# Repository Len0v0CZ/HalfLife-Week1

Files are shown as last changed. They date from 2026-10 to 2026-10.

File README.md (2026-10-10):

# Macro Keyboard

A compact macro keyboard featuring 3 keys and 1 rotary encoder for task automation.
## Components
- Raspberry Pi Pico
- 3x Mechanical Switches
- 1x KY-040 Rotary Encoder
- Custom PCB
- 3D-printed case (base and lid)

Case
PCB

## Hardware Assembly
1. Solder the Pico, switches, and encoder to the PCB.
2. Mount the assembled PCB into the 3D-printed base using the M3 sized studs.
3. Attach the lid.

## Software Setup
1. Install CircuitPython on the Raspberry Pi Pico, more precisely it uses `adafruit_hid` library.
2. Save the Python script as `code.py` in the root directory.

## Usage
The rotary encoder adjusts the system volume and its button toggles mute. The three mechanical switches can be bound in `code.py`.

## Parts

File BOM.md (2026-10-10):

# Macro keyboard – bill of materials

<!-- Generated by Half Life from project cmuvl2h3h01gk01pys8nkxjlp. Edits here are overwritten on the next sync. -->
<!-- Generated: 2026-10-10T14:33:19.368Z -->

> [!NOTE]
> This parts list is mirrored from [Half Life](https://halflife.hackclub.com). Editing it here will not change the platform's copy, and the next sync overwrites this file.

| Week | Tier | Parts funding |
| --- | --- | --- |
| Week 1 | Tier 1 | $30.00 |

| Part | What it's for | Qty | Unit | Total | Vendor |
| --- | --- | --- | --- | --- | --- |
| [Raspberry Pico](https://rpishop.cz/raspberry-pi-pico/5117-raspberry-pi-pico.html) | main control board | 1 | $5.00 | $5.00 | [RpiShop](https://rpishop.cz/raspberry-pi-pico/5117-raspberry-pi-pico.html) |
| [Rotary encoder](https://rpishop.cz/enkodery/1329-rotacni-enkoder-ky-040-s-tlacitkem.html) | Volume control | 1 | $2.00 | $2.00 | [Rpishop](https://rpishop.cz/enkodery/1329-rotacni-enkoder-ky-040-s-tlacitkem.html) |
| [PCB](https://cart.jlcpcb.com/quote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) | the main board | 1 | $4.00 | $4.00 | [JLPCB](https://cart.jlcpcb.com/quote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) |
| **Parts subtotal** | — | — | — | **$11.00** | — |
| **Tax & shipping** | — | — | — | **$16.77** | — |
| **Total** | — | — | — | **$27.77** | — |

$2.23 left of the tier's funding.

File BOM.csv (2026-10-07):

Item | Part | Description | Quantity
1 | Custom PCB | PCB for the project | 1
2 | Cherry MX Switch | Mechanical switch | 3
3 | Rotary Encoder | Rotary encoder | 1
4 | Raspberry Pi Pico | microcontroller | 1
5 | 3D Printed Case Parts | Enclosure components | 1 set

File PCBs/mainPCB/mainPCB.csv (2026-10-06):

Reference | Qty | Value | DNP | Exclude from BOM | Exclude from Board | Exclude from Simulation | Exclude from Position Files | Footprint | Datasheet
A1 | 1 | RaspberryPi_Pico |  |  |  |  | ${EXCLUDE_FROM_POS_FILES} | Module:RaspberryPi_Pico_Common_Unspecified | https://datasheets.raspberrypi.com/pico/pico-datasheet.pdf
SW1 | 1 | RotaryEncoder_Switch |  |  |  |  | ${EXCLUDE_FROM_POS_FILES} | Rotary_Encoder:RotaryEncoder_Alps_EC11E-Switch_Vertical_H20mm_CircularMountingHoles
SW2,SW3,SW4 | 3 | SW_Push |  |  |  |  | ${EXCLUDE_FROM_POS_FILES} | Button_Switch_Keyboard:SW_Cherry_MX_1.00u_Plate

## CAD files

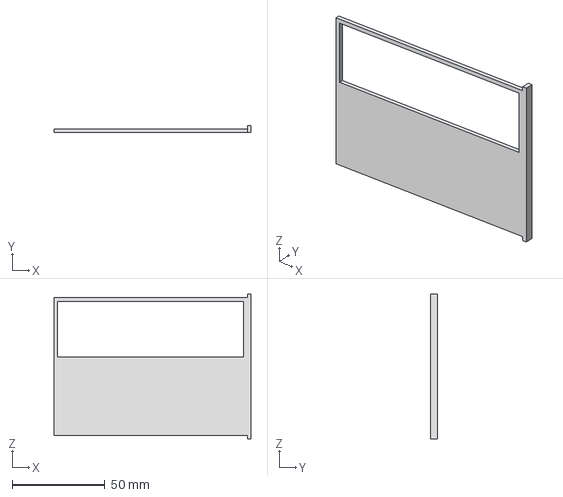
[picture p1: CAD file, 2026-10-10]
Case/STEPs/Lid.stp
106.0 x 4.00 x 78.0 mm

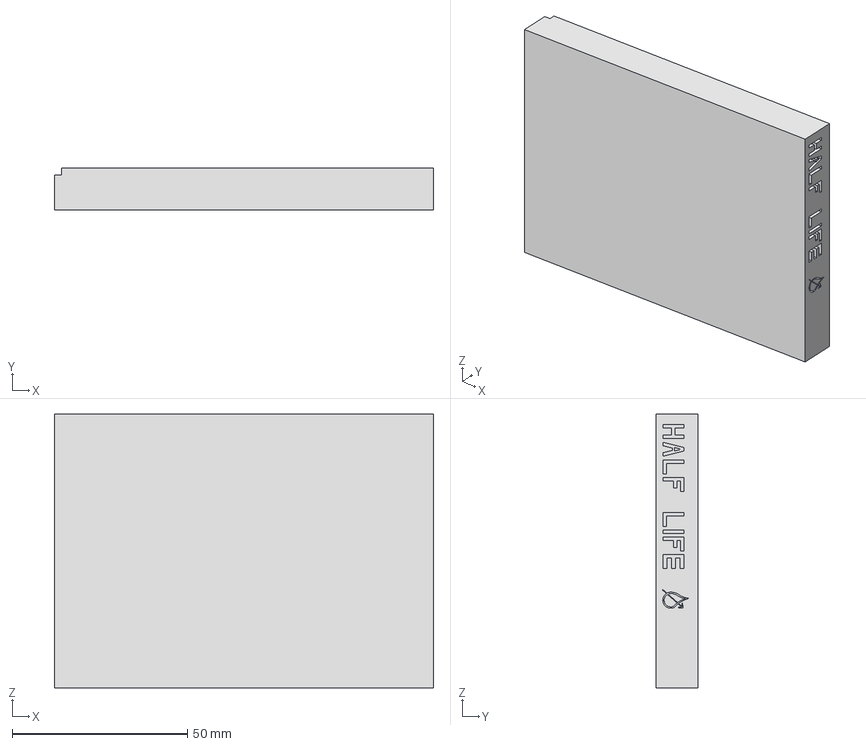
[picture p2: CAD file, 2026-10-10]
Case/STEPs/BasePlate.stp
108.0 x 12.0 x 78.0 mm

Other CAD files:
Case/Inventor/BasePlate.ipt
Case/Inventor/CASE.iam
Case/Inventor/Lid.ipt
Case/OldVersions/BasePlate.0005.ipt
Case/STLs/BasePlate.stl
Case/STLs/Lid.stl

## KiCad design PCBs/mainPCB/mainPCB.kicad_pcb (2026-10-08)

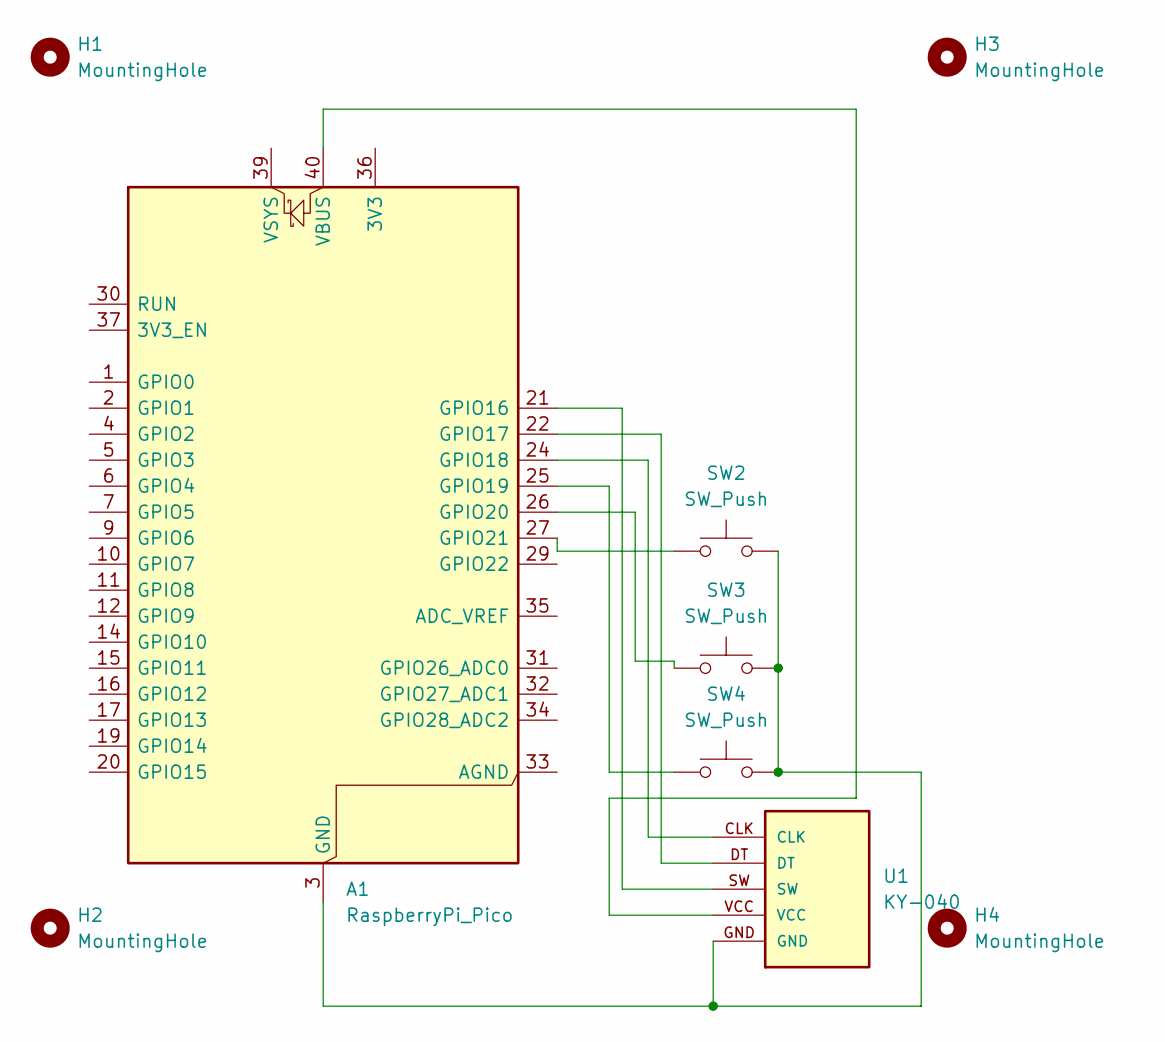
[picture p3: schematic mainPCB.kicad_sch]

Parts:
A1: RaspberryPi_Pico; RaspberryPi_Pico_Common_Unspecified
H1, H2, H3, H4: MountingHole; MountingHole_3.2mm_M3_DIN965
SW2, SW3, SW4: SW_Push; SW_Cherry_MX_1.00u_Plate
U1: KY-040; KY-040-PORT

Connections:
unnamed: A1.3 (GND), A1.8 (GND), A1.13 (GND), A1.18 (GND), A1.23 (GND), A1.28 (GND), A1.38 (GND), SW2.2, SW3.2, SW4.2, U1.GND
unnamed: A1.21 (GPIO16), U1.SW
unnamed: A1.22 (GPIO17), U1.DT
unnamed: A1.24 (GPIO18), U1.CLK
unnamed: A1.25 (GPIO19), SW4.1
unnamed: A1.26 (GPIO20), SW3.1
unnamed: A1.27 (GPIO21), SW2.1
unnamed: A1.40 (VBUS), U1.VCC

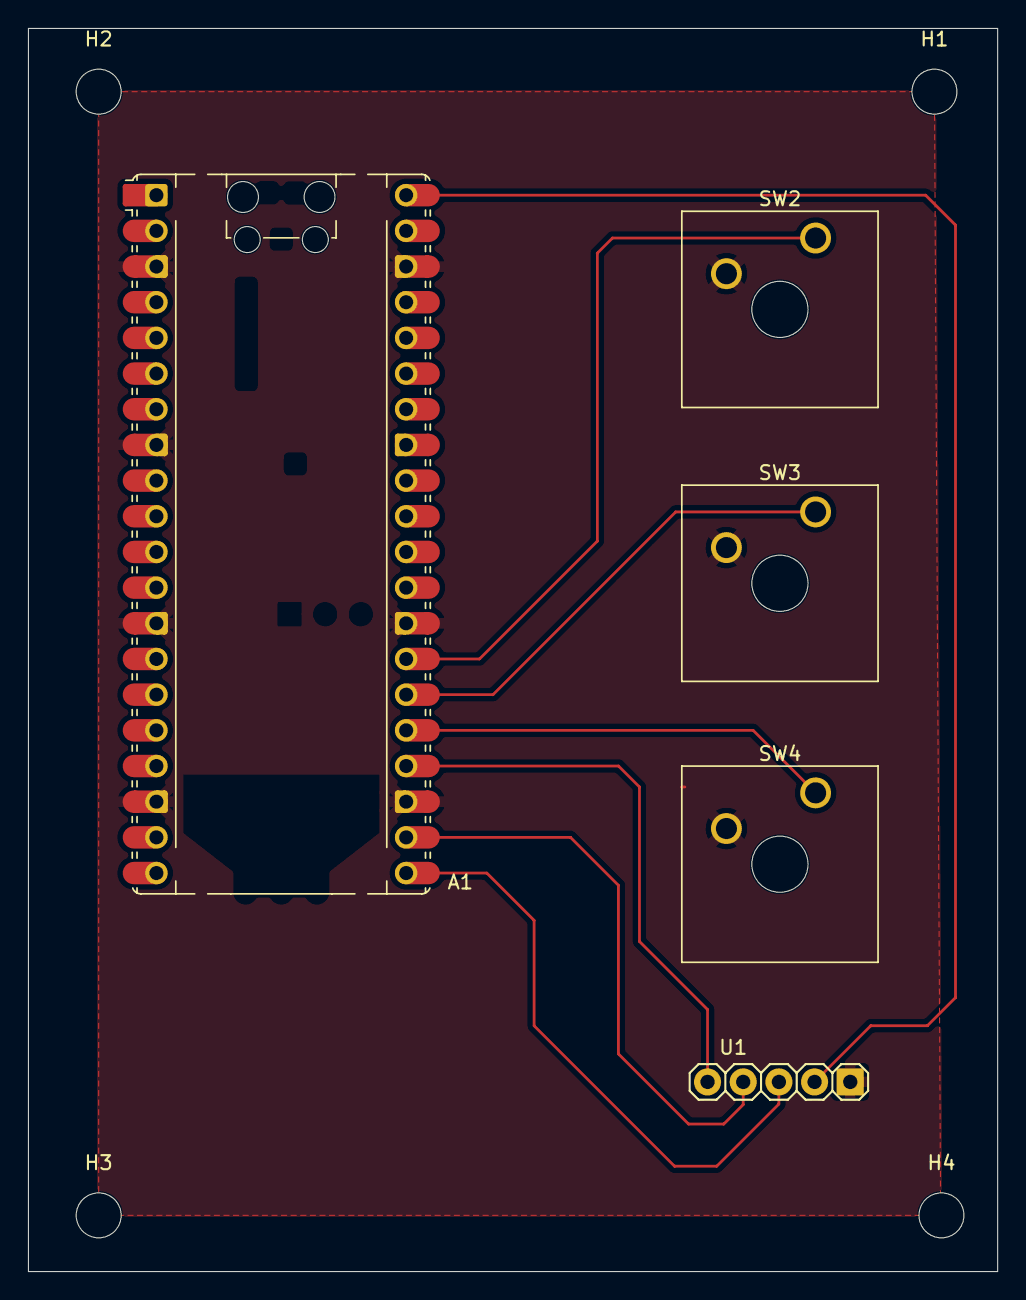
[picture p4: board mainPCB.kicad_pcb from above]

Board: 2 copper layers, 69.0 x 88.5 mm, 9 parts (0 on the bottom side), 8 nets.

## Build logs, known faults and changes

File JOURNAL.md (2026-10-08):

# Macro keyboard – devlog

<!-- Generated by Half Life from project cmuvl2h3h01gk01pys8nkxjlp. Edits here are overwritten on the next sync. -->
<!-- Generated: 2026-10-08T17:35:38.110Z -->

> [!NOTE]
> This devlog is mirrored from [Half Life](https://halflife.hackclub.com). Editing it here will not change the platform's copy, and the next sync overwrites this file.

> a small macro keyboard with 3 keys and 1 knob for automation of repeated actions

| Week | Tier | Hours logged | Entries |
| --- | --- | --- | --- |
| Week 1 | Tier 1 | 9.2h | 3 |

## Contents

1. [2026-10-06 – # October 6](#2026-10-06-october-6)
2. [2026-10-08 – # October 8 part 1](#2026-10-08-october-8-part-1)
3. [2026-10-08 – # October 8 part 2](#2026-10-08-october-8-part-2)

## Design

### 2026-10-06 – # October 6

**4h**

# October 6
## KiCAD time!
After i decided i wanted to do macro keyboard, i started studying what that contains. i found out that PCBs are best made in KiCAD, so i went right in. At first i was quite confused, i couldnt figure out almost anything. quick indian tutorial on youtube told me i needed footprint.. but what are those?
chaos in KiCAD
*Ah! footprint is the space on PCB each component takes up* I yelled and startled my parents a bit.
after that it all made sense. A bit of tutorial here, a bit of searching for help there and after few hours i finally had complete footprints of all my components.
finally understood footprints
after that it was time to go to the PCB editor, where i found out its whole another program, so i needed to learn from scratch once again. After shuffling stuff around to bettter organize it i found one, that didnt look awful, so I decided to use it.
finally in PCB editor
In the end i moved stuff further apart and i cut the board to the required size, next on the list was **tracing**, my arch nemesis as it seemed
Layout finalization
 After reading few articles about tracing and common ground as a big plane i gave it a try, my first attempts werent very succesful and my traces were crossing, which wouldnt work,
but after some time it suddenly snaped, everything went smoothly after that and i finally had a traced PCB.
3D view of PCB
I decided to play a little bit more and added 3D models for the switches, which looks great, but I wasnt able to find a single usable rotary encoder model in **.step** format.
I really hope the Pico was a good choice i wont regret later, but its the only one i worked with before.

### TL:DR
* **Finished PCB**
* *trouble with tracing*
* many tutorials watched
* Hey reviewer, hope you are having a great day
* a bit confused about rotary encoder connection: need to do more research

### 2026-10-08 – # October 8 part 1

**1.2h**

# October 8 part 1
## PCB fixing time
as it turns out, i made a mistake during my PCB designing session and connected my rotary encoder incorrectly + i gave it wrong footprint

original design

so i went back into KiCAD and fixed the design in scheme planner

fixed design

next step was fixing it on the PCB itself, which will be harder as it has already been made to the perfect size, this will only make it worse.

fixed PCB scheme

Okay, the space wasnt as big of an issue as i thought it would be, but it still was a challange to fit it correctly inside my form factor, but the tracing was pain yet again, ground is really confusing!

final PCB scheme

here is the finished PCB view, and the next image is the 3D view with rotary encoder 3D model.

3D view

### TL:DR
* **fixed** PCB design and 3D view
* retraced rotary encoder

### 2026-10-08 – # October 8 part 2

**4h**

# October 8 part 2
## CAD time
Since i have my PCB ready, i decided that the next step is designing a nice housing for my project. I decided to use Autodesk Inventor for it.
Inventor

Using Patterns i made my PCBs footprint in inventor

Pattern

Next up was finishing the first sketch, extruding it to correct height and checking if everything is correct

first sketch extruded

I decided i wanted to create text on the case, so i am writing HALF LIFE on the side of the case

Text sketch

After finishing lettering a went ahead and used autoconstraints to lock my letters in place (what a mess of constraints this is :D)

Lettering

 next up is Half Life logo, which will be very hard for me, because im terrible when it comes to drawing

Half life logo

well, it 100% isnt great, but after 30 minutes of work on this logo alone!  I am done, i cant anymore.

Next up will be cover, im thinking of doing a simple slider, that will be held by the walls, but before that i need to edit the walls

finished base

For now, this will be the finished base, one last change was M3 screw studs instead of holes, which gives me *screwless* instalation.

### Onto the 2nd part of the case
**The lid**

I started by taking measurements of my base, so i know how big the lid needs to be

Lid

this is the plain lid, tommorow i will work on decorating it

combined
Last picture, this time combined both pieces into how may the final case look like

### TL:DR
* CAD designing bottom **case** with text and **half life logo**
* started designing the lid, *plain* for now, will add more tomorrow

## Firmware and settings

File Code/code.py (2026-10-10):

import time
import board
import digitalio
import rotaryio
import usb_hid
from adafruit_hid.keyboard import Keyboard
from adafruit_hid.keycode import Keycode
from adafruit_hid.consumer_control import ConsumerControl
from adafruit_hid.consumer_control_code import ConsumerControlCode

keyb = Keyboard(usb_hid.devices)
cons_control = ConsumerControl(usb_hid.devices)
enc = rotaryio.IncrementalEncoder(board.GP18, board.GP17)
last_p = enc.position
button_pins = {
    "SW1": board.GP16,
    "SW4": board.GP19,
    "SW3": board.GP20,
    "SW2": board.GP21
}

buttons = {}
for name, pin in button_pins.items():
    bt = digitalio.DigitalInOut(pin)
    bt.direction = digitalio.Direction.INPUT
    bt.pull = digitalio.Pull.UP
    buttons[name] = {"GPIO": bt, "Last": True}

macros = {
    "SW4": (Keycode.CONTROL, Keycode.A),
    "SW3": (Keycode.CONTROL, Keycode.C),
    "SW2": (Keycode.CONTROL, Keycode.V),
}

while True:
    current_p = enc.position
    p_delta = current_p - last_p

    if p_delta > 0:
        for i in range(p_delta):
            cons_control.send(ConsumerControlCode.VOLUME_INCREMENT)
    elif p_delta < 0:
        for i in range(abs(p_delta)):
            cons_control.send(ConsumerControlCode.VOLUME_DECREMENT)

    last_p = current_p

    for name, data in buttons.items():
        current_state = data["GPIO"].value
        if not current_state and data["Last"]:
            if name == "SW1":
                cons_control.send(ConsumerControlCode.MUTE)
            else:
                keyb.press(*macros[name])
            data["Last"] = False
        elif current_state and not data["Last"]:
            if name != "SW1":    
                keyb.release_all()
            data["Last"] = True

    time.sleep(0.05)

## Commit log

2026-10-06 Finished PCB
    finished PCB for raspberry Pico, 3 switches and rotary encoder
    [mainPCB.csv, mainPCB.kicad_pcb, mainPCB.kicad_sch]
2026-10-07 reorganization
    files and folders reorganised for better clarity
    [BOM.csv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]
2026-10-08 fixed PCB
    retraced few traces, reworked rotary encoder to completely different design
    [mainPCB.kicad_pcb, mainPCB.kicad_sch]
2026-10-08 small fixes for PCB
    [mainPCB.kicad_pcb]
2026-10-08 CAD
    added base plate and lid for macro keyboard container
    [BasePlate.0005.ipt, BasePlate.ipt, CASE.iam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]
2026-10-10 Code added
    [BasePlate.stl, BasePlate.stp, Lid.stl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]
